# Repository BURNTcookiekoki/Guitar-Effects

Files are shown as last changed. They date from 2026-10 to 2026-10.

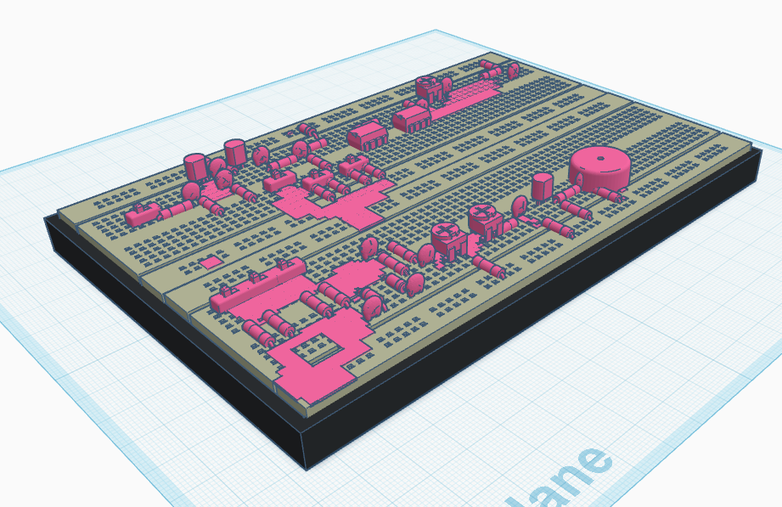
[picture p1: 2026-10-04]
Photos/CE4.png

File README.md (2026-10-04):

[Final2.csv](https://github.com/user-attachments/files/33020397/Final2.csv)Guitar Pedal - Modded Boss DS1

Breadboard1

The Modded Boss DS1 pedal includes 3 knobs gain, level and tone with 8 extra options to change the type of distortion and bypass switch

I have created this project as both buying many analog pedals or a whole multiboard can be expensive so I thought about creating a cheaper alternative with more options so I dont need to change pedals.

It features 3 potentiometers to control gain, level and tone with an extra 8 options ( 4 for each option ) to change the intensity or power of the distortion too gives sounds of metal, blues and pushed pedal sounds, also has a switch to bypass the signal.

CE4
This is the image of my 3d model case which is open as I want it to be modular or recyclable; so I can change the board to create new pedals. It has space for 2 830pin breadboards which can carry components as well as a 9v input, and 2 mono 6.35mm or 1/4" female jacks for input and output of guitar.

[Boss DS1 (1).pdf](https://github.com/user-attachments/files/33019150/Boss.DS1.1.pdf)
This PDF is the wiring schematic I created on Tinkercad because both Fusion and Livespice is hard to look at.

[Uploading Final2.csv…](Component,Qty,Supplier,Part / Link,

830-point breadboard,2,Jaycar,PB8815 - https://www.jaycar.co.nz/arduino-compatible-breadboard-with-830-tie-points/p/PB8815

9V alkaline battery,1,Jaycar,SB2423 - https://www.jaycar.co.nz/eclipse-9v-alkaline-battery/p/SB2423

"10kΩ resistor, 0.5W, 8-pack",1,Jaycar,RR0596 - https://www.jaycar.co.nz/10k-ohm-0-5-watt-metal-film-resistors-pack-of-8/p/RR0596

"1kΩ resistor, 0.5W, 8-pack",1,Jaycar,RR0572 - https://www.jaycar.co.nz/1k-ohm-0-5-watt-metal-film-resistors-pack-of-8/p/RR0572

"100kΩ resistor, 0.5W, 8-pack",1,Jaycar,RR0620 - https://www.jaycar.co.nz/100k-ohm-0-5-watt-metal-film-resistors-pack-of-8/p/RR0620

"470kΩ resistor, 0.5W, 8-pack",1,Jaycar,RR0636 - https://www.jaycar.co.nz/470k-ohm-0-5-watt-metal-film-resistors-pack-of-8/p/RR0636

"47kΩ resistor, 0.5W, 8-pack",1,Jaycar,RR0612 - https://www.jaycar.co.nz/47k-ohm-0-5-watt-metal-film-resistors-pack-of-8/p/RR0612

"22Ω resistor, 0.5W, 8-pack",1,Jaycar,RR0532 - https://www.jaycar.co.nz/22-ohm-0-5-watt-metal-film-resistors-pack-of-8/p/RR0532

"3.3kΩ resistor, 0.5W, 8-pack",1,Jaycar,RR0584 - https://www.jaycar.co.nz/3-3k-ohm-0-5-watt-metal-film-resistors-pack-of-8/p/RR0584

"1.5kΩ resistor, 0.5W, 8-pack",1,Jaycar,RR0576 - https://www.jaycar.co.nz/1-5k-ohm-0-5-watt-metal-film-resistors-pack-of-8/p/RR0576

"2.2kΩ resistor, 0.5W, 8-pack",1,Jaycar,RR0580 - https://www.jaycar.co.nz/2-2k-ohm-0-5-watt-metal-film-resistors-pack-of-8/p/RR0580

"4.7kΩ resistor, 0.5W, 8-pack",1,Jaycar,RR0588 - https://www.jaycar.co.nz/4-7k-ohm-0-5-watt-metal-film-resistors-pack-of-8/p/RR0588

"6.8kΩ resistor, 0.5W, 8-pack",1,Jaycar,RR0592 - https://www.jaycar.co.nz/6-8k-ohm-0-5-watt-metal-film-resistors-pack-of-8/p/RR0592

47µF capacitor,1,Jaycar,RE6332 - https://www.jaycar.co.nz/47uf-35vdc-low-esr-electrolytic-capacitor/p/RE6332

47nF capacitor,3,Jaycar,RG5105 - https://www.jaycar.co.nz/47nf-100vdc-polyester-capacitor/p/RG5105

470nF capacitor,3,Jaycar,RG5165 - https://www.jaycar.co.nz/470nf-35vdc-tantalum-capacitor/p/RZ6626

250pF capacitor,1,AliExpress,250pF, https://www.aliexpress.com/item/1005010509208757.html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"order"%3A"11"%2C"eval"%3A"1"%2C"fromPage"%3A"search"%7D&pdp_npi=6%40dis%21NZD%2111.78%2111.19%21%21%2143.36%2141.19%21%402101d2e717910968870695546e0e7e%2112000052639323740%21sea%21NZ%210%21ABX%211%210%21n_tag%3A-29910%3Bd%3Abebf9545%3Bm03_new_user%3A-29895&curPageLogUid=UDYDKjHd2Bku&utparam-url=scene%3Asearch%7Cquery_from%3A%7Cx_object_id%3A1005010509208757%7C_p_origin_prod%3A

65nF capacitor,1,Jaycar, - https://www.jaycar.co.nz/68nf-100vdc-polyester-capacitor/p/RG5115

100pF capacitor,1,Jaycar,RC5324 - https://www.jaycar.co.nz/100pf-50vdc-ceramic-capacitors-pack-of-2/p/RC5324

10nF capacitor,1,Jaycar,RM7065 - https://www.jaycar.co.nz/10nf-100vdc-mkt-polyester-capacitor/p/RM7065

22nF capacitor,1,Jaycar,RG5085 - https://www.jaycar.co.nz/22nf-100vdc-polyester-capacitor/p/RG5085

100nF capacitor,1,Jaycar,RG5125 - https://www.jaycar.co.nz/100nf-100vdc-polyester-capacitor/p/RG5125

1µF capacitor,1,Jaycar,RC5499 - https://www.jaycar.co.nz/1uf-50vdc-monolithic-capacitor/p/RC5499

BC547 NPN transistor,3,Jaycar,ZT2152 - https://www.jaycar.co.nz/bc547-npn-transistor/p/ZT2152

LM741 op-amp,2,Jaycar,ZL3741 - https://www.jaycar.co.nz/lm741-general-purpose-op-amp-linear-ic/p/ZL3741

"1N4148/1N914 diode, 5-pack",1,Jaycar,ZR1100 - https://www.jaycar.co.nz/1n4148-1n914-signal-diode-pack-of-5/p/ZR1100

100kΩ linear potentiometer,2,Jaycar,RP3518 - https://www.jaycar.co.nz/100k-ohm-linear-b-single-gang-24mm-potentiometer/p/RP3518

20kΩ linear potentiometer,1,AliExpress,"B20K linear - https://www.aliexpress.com/item/1005012540659162.html

DPDT,7,Jaycar,SS0821  - https://www.jaycar.co.nz/miniature-dpdt-panel-mount-switch/p/SS0821

Female 1/4in / 6.35mm mono chassis socket,2,Jaycar,PS0162 - https://www.jaycar.co.nz/6-5mm-mono-chassis-socket-unswitched/p/PS0162

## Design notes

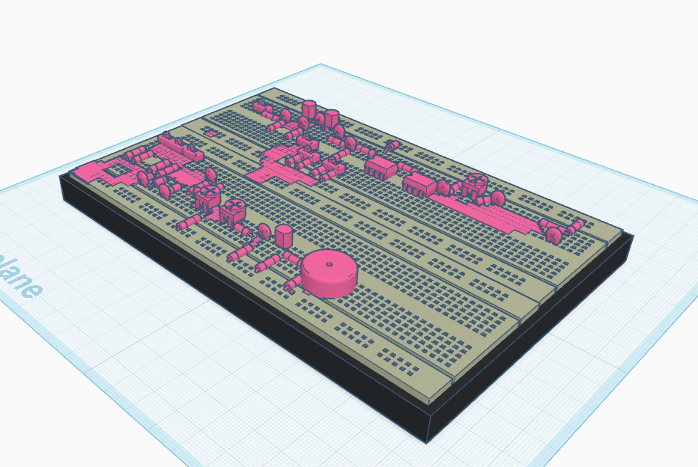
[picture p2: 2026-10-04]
Photos/CE1.png

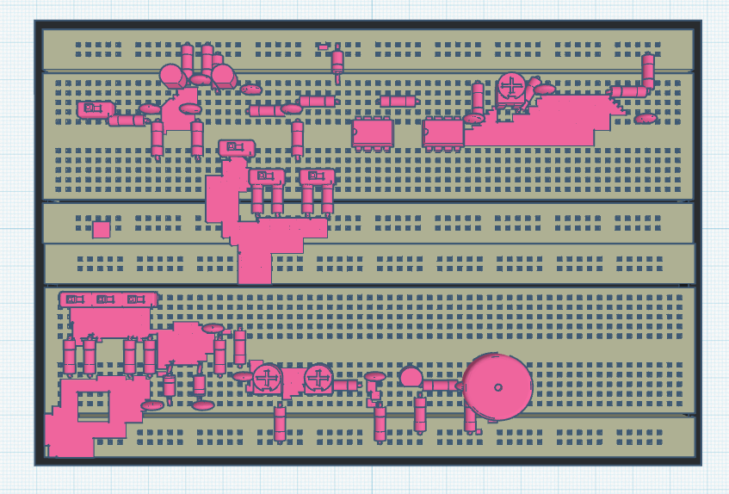
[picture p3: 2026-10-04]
Photos/CE5.png

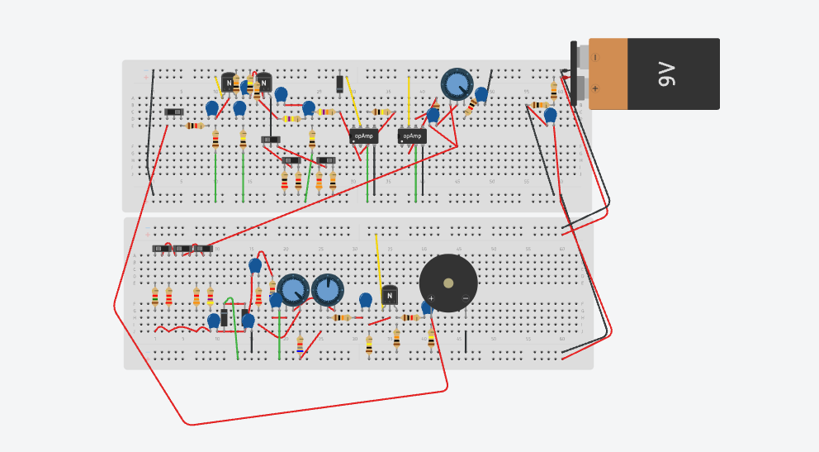
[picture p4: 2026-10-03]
Photos/Breadboard2.png

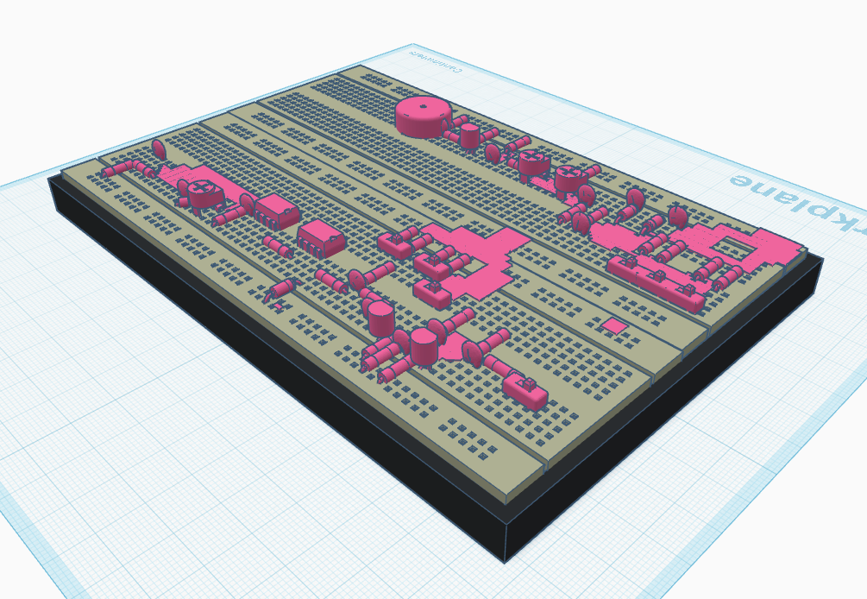
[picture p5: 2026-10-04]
Photos/CE3.png

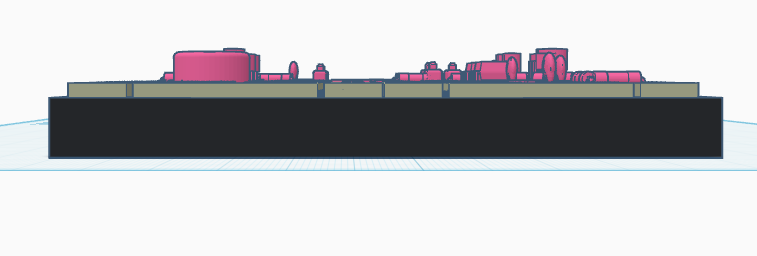
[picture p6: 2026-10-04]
Photos/CE6.png

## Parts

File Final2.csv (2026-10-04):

Component | Qty | Supplier | Part / Link | Unit Price NZD | Subtotal NZD
830-point breadboard | 2 | Jaycar | PB8815 - https://www.jaycar.co.nz/arduino-compatible-breadboard-with-830-tie-points/p/PB8815 | 26.9 | 53.8
9V alkaline battery | 1 | Jaycar | SB2423 - https://www.jaycar.co.nz/eclipse-9v-alkaline-battery/p/SB2423 | 8.9 | 8.9
10kO resistor, 0.5W, 8-pack | 1 | Jaycar | RR0596 - https://www.jaycar.co.nz/10k-ohm-0-5-watt-metal-film-resistors-pack-of-8/p/RR0596 | 1 | 1
1kO resistor, 0.5W, 8-pack | 1 | Jaycar | RR0572 - https://www.jaycar.co.nz/1k-ohm-0-5-watt-metal-film-resistors-pack-of-8/p/RR0572 | 1 | 1
100kO resistor, 0.5W, 8-pack | 1 | Jaycar | RR0620 | 1 | 1
470kO resistor, 0.5W, 8-pack | 1 | Jaycar | RR0636 | 1 | 1
47kO resistor, 0.5W, 8-pack | 1 | Jaycar | RR0612 | 1 | 1
22O resistor, 0.5W, 8-pack | 1 | Jaycar | RR0532 | 1 | 1
3.3kO resistor, 0.5W, 8-pack | 1 | Jaycar | RR0584 | 1 | 1
1.5kO resistor, 0.5W, 8-pack | 1 | Jaycar | RR0576 | 1 | 1
2.2kO resistor, 0.5W, 8-pack | 1 | Jaycar | RR0580 | 1 | 1
4.7kO resistor, 0.5W, 8-pack | 1 | Jaycar | RR0588 | 1 | 1
6.8kO resistor, 0.5W, 8-pack | 1 | Jaycar | RR0592 | 1 | 1
47µF capacitor | 1 | Jaycar | RE6332 | 0.5 | 0.5
47nF capacitor | 3 | Jaycar | RG5105 | 0.4 | 1.2
470nF capacitor | 3 | Jaycar | RG5165 | 0.5 | 1.5
250pF capacitor | 1 | AliExpress | Exact 250pF through-hole ceramic, ~https://www.aliexpress.com/w/wholesale-250pf-capacitor.html | 1 | 1
65nF capacitor | 1 | AliExpress | Exact 65nF through-hole film, ~https://www.aliexpress.com/w/wholesale-65nf-capacitor.html | 1 | 1
100pF capacitor | 1 | Jaycar | RC5324 | 0.5 | 0.5
10nF capacitor | 1 | Jaycar | RM7065 | 0.4 | 0.4
22nF capacitor | 1 | Jaycar | RG5085 | 0.4 | 0.4
100nF capacitor | 1 | Jaycar | RG5125 | 0.4 | 0.4
1µF capacitor | 1 | Jaycar | RC5499 | 0.9 | 0.9
BC547 NPN transistor | 3 | Jaycar | ZT2152 | 0.4 | 1.2
LM741 op-amp | 2 | Jaycar | ZL3741 | 2.3 | 4.6
1N4148/1N914 diode, 5-pack | 1 | Jaycar | ZR1100 | 1.1 | 1.1
100kO linear potentiometer | 2 | Jaycar | RP3518 | 4.6 | 9.2
20kO linear potentiometer | 1 | AliExpress | B20K linear, ~https://www.aliexpress.com/w/wholesale-20k-potentiometer.html | 1.5 | 1.5
DPDT | 7 | Jaycar | SS0821 | 2 | 14
Female 1/4in / 6.35mm mono chassis socket | 2 | Jaycar | PS0162 | 2.4 | 4.8

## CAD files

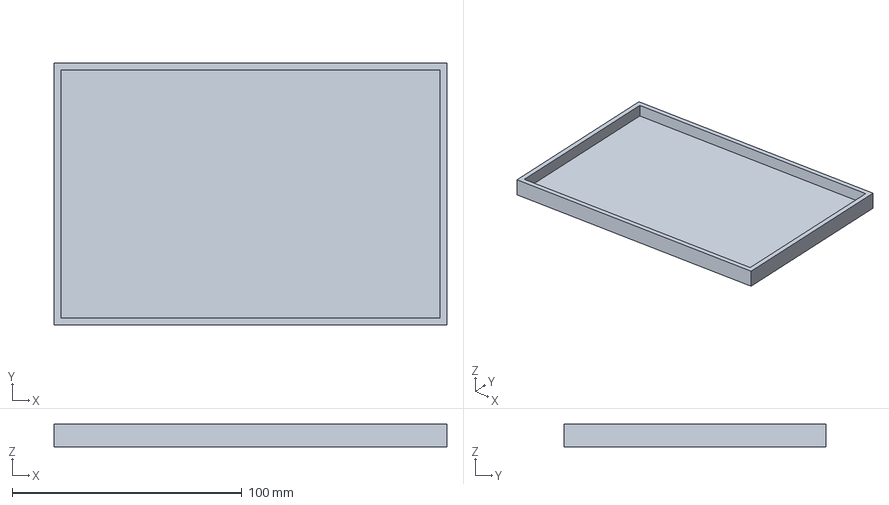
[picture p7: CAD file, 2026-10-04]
Cad/v1-Case-for-Guitar-pedal-project-2.step
171.0 x 114.0 x 10.0 mm

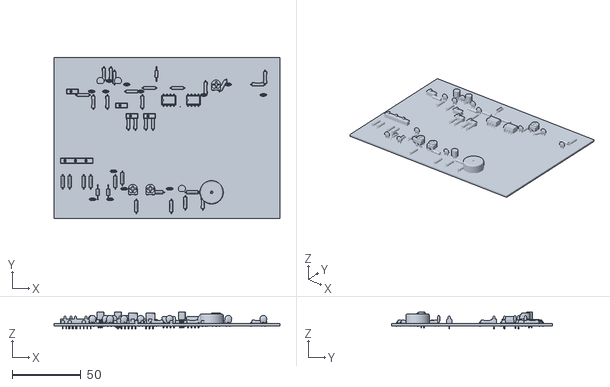
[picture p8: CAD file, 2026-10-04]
Cad/Boss DS1 (1).stl
163.8 x 117.0 x 12.0

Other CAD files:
Cad/v1-ELECTRONIC-Case-for-Guitar-pedal-project.step
Cad/v1 Case for Guitar pedal project (2).stl
Cad/v1 ELECTRONIC+ Case for Guitar pedal project.stl

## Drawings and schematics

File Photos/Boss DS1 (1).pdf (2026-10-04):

A

1 | 2 | 3 | 4 | 5 | 6

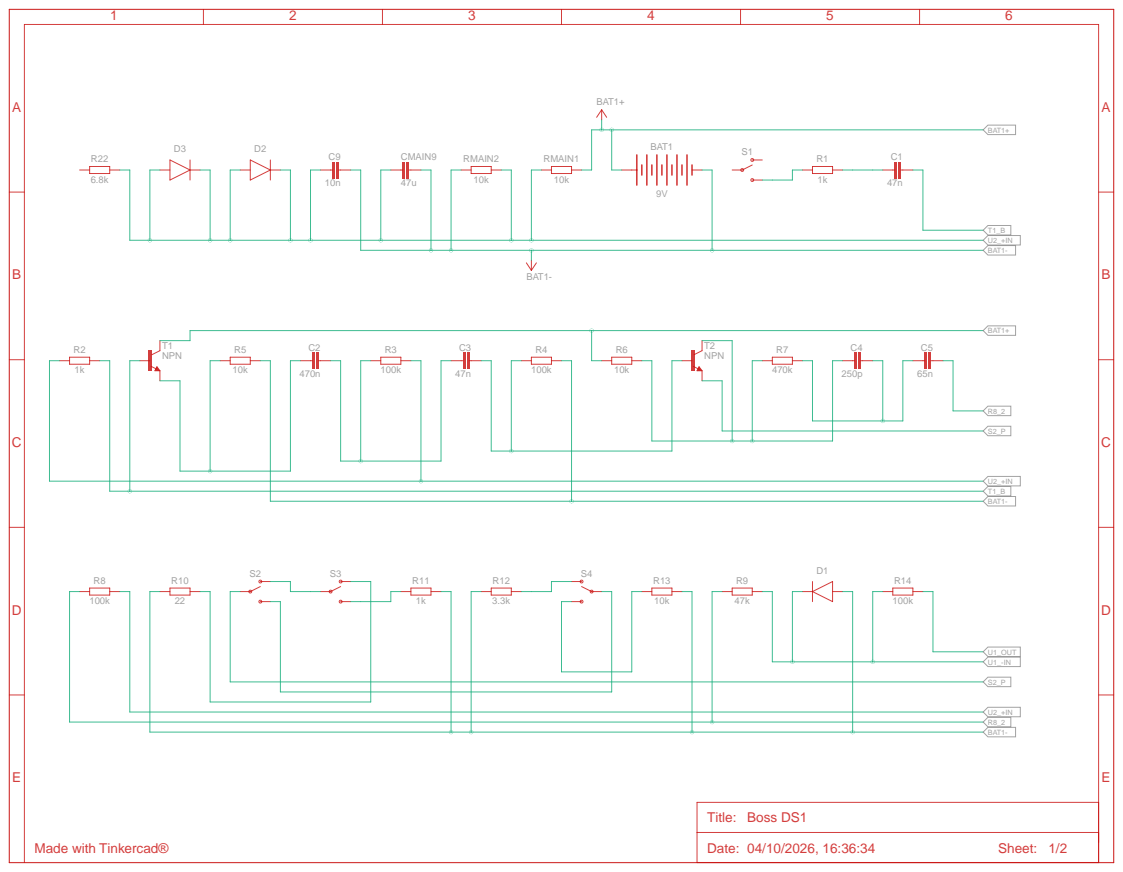
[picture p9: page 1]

A

1 | 2 | 3 | 4 | 5 | 6

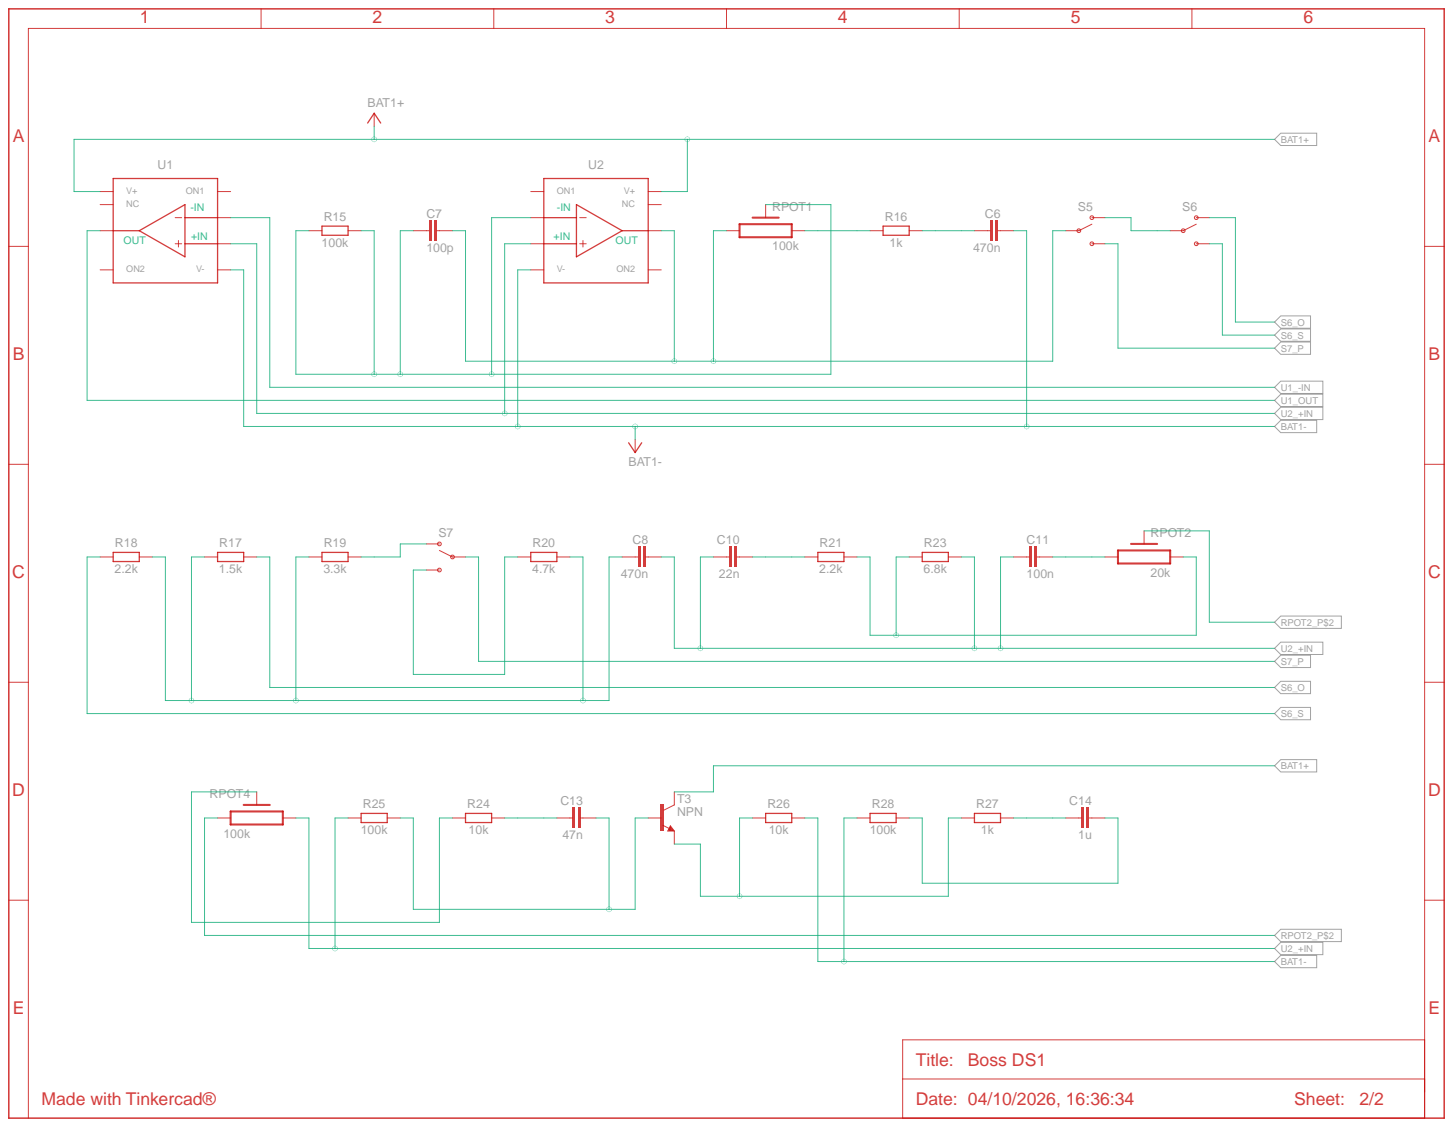
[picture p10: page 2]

BAT1+

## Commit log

2026-09-30 Sync Guitar Effects on Board from Half Life
2026-10-01 Enhance README with Boss DS1 pedal details
    Added information about Boss DS1 pedal modifications and included additional schematics.
2026-10-03 Create Case photo
2026-10-04 Add input component to BOM
    [bom final.csv]
